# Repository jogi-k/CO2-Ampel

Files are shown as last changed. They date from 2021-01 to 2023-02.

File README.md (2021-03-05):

# CO2-Ampel

Ziel : 3 verschiedene Systeme für eine CO2-Ampel

Alle nutzen den CO2-Sensor von Sensirion, der via I2C-Bus folgende Daten ausgibt:

* CO2-Konzentration in ppm
* Temperatur in °C
* Luftfeuchte in %

Die drei Ampeln nutzen ansonsten, was der Bastler-Haushalt so hergibt.

## System 1 (ist fertig) :

Siehe [hier im Unterverzeichnis Teensy/CO2_Ampel](Teensy/CO2_Ampel/README.md)

* Teensy-LC
* 4 * 7-Segment-Anzeigen mit Neo-Pixeln, ist also gleichzeitig die Ampel, da die Farben angezeigt werden

## System 2 (ist fertig)

und sieht so aus:

* Teensy LC 
* Neo-Pixel-Ring mit 16 LEDs, pro 100 ppm 1 LED bis max 1699 ppm unterscheidbar, farbkodierte Wertebereiche
* OLED-Display 0.91" , 128 x 32, für Ausgabe der genauen CO2-Konzentration 
* Ein BCD-Dreh-Encoder für die Helligkeit der Neopixel-LEDs e Grafik-Anzeige mit Zeit ...

Siehe [hier im Unterverzeichnis Teensy/CO2_Ampel_OLed](Teensy/CO2_Ampel_OLed/README.md)

## System 3:

* Raspberry Pi (mal schauen, welcher...)
* grosse USB-Ampel von Cleware
* 3.5 " LCD für Raspi
* evt. je nach Aufstellungs-Ort, auch noch eine RTC

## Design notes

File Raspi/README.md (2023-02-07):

# CO2-Ampel am Raspberry-Pi

* Raspberry Pi
* USB-Ampel von Cleware
* CO2-Sensor SCD 30 
* Display tbd

## Software

* SCD30-I2C Python - SW : https://pypi.org/project/scd30-i2c
* USB-Ampel : https://github.com/jenszech/StatusLight
* bzw : 

## Other SCD30-Software

* Nutze inzwischen (co2-ampel-II.py) den Treiber-code von sensirion selbst

## Zweiter I2C-Bus

Moechte nun 2 (besser noch 3) SCD 30 Sensoren mal eine Woche an der frischen Luft laufen lassen um zu sehen, inwieweit sich die Messwerte angleichen.

Der Raspberry Pi hat zwei I2C-Busse eingebaut, der andere (I2C-Bus 0) muss jedoch erst per Config eingeschaltet werden.

Mehr Infos dazu : https://www.woodgears.ca/tech/i2c.html
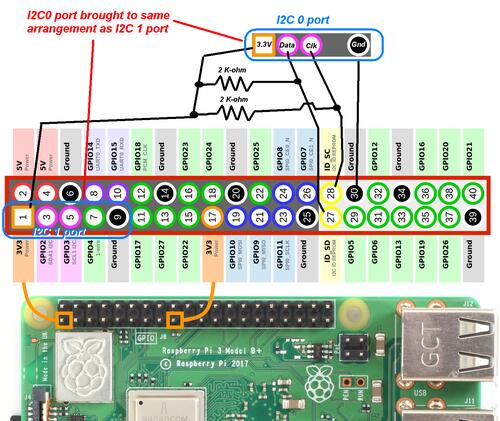
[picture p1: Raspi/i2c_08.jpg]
Bild
Anschluss : 

### Dritter I2C-Bus 

Fuer den 3ten Sensor habe ich mir einen exteren USB2I2C-Adapter besorgt.  
Mehr Infos dazu gibt es u.a im Raspberry Pi Geek Magazin:

* https://www.raspberry-pi-geek.de/ausgaben/rpg/2020/06/i-2-c-teil-31-usb-i-2-c-modul-mcp23017/
* http://www.chinalctech.com/cpzx/Programmer/Serial_Module/266.html
* 
und hier

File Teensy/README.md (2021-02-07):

# Teensy LC USB-Ampel

## 1. Teensy LC mit Neosegments

* Sensor Sensirion SCD30 für CO2-Messung
* 2 Doppelsegmente Neosegments, 7-Segment-Anzeige mit Farbe
* Das geht und ist im Einsatz in der Schule, Details siehe [hier](CO2_Ampel/README.md) 

## 2. Teensy LC mit Neopixel-Ring und kleinem OLED-Display

* Sensor Sensirion SCD30 für CO2-Messung
* Neopixel-Ring mit 16 RGB-Leds, je LED für 100 ppm
* Die LEDs wechseln natürlich auch die Farbe
* zusätzlich ein Mini-OLED-Display, das die ppm-Werte anzeigt
* Das ist gerade im Aufbau, Einzel-SW-Teile gehen schon, siehe [hier](CO2_Ampel_OLed/README.md)

## 3. Teensy LC mit ePaper-Shield 

* Epaper-shield von Crowd-Supply
* Software von, mit Patch von mir: 
* Graph-Routines von https://create.arduino.cc/projecthub/andreiflorian/tft-graphing-live-history-graphs-744f3b
* Ist noch stark im Aufbau, die Epaper-Shield-SW braucht noch nen weiteren Patch* Die Graph-Routines dienen als Inspiration, sind selbst aber etwas buggy und können so nicht verwendet werden.

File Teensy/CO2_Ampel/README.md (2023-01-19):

# Teensy LC USB-Ampel mit Neosegments

* Der Sensirion SCD30 CO2-Sensor wird mit I2C angesprochen
* dafür gibt es eine Library, SparkFun_SCD30_Arduino_Library 
* diese wurde von mir gepatcht, um mit anstatt mit der wire-I2C-library die besser für Teensy 3 / Teensy LC geeignete i2c_t3 - Library zu verwenden
* Der Patch ist inzwischen auf dem Master-Branch von Sparkfun
* Muss jedoch explizit im Headerfile eingeschaltet werden, siehe  // #define USE_TEENSY3_I2C_LIB  
* Die Anzeige wurde über die (leider nicht mehr verfügbaren) Neo-Segments von crowdsupply realisiert : [https://www.crowdsupply.com/maksmakes/neosegment](https://www.crowdsupply.com/maksmakes/neosegment)

## Das Pinout des SCD30

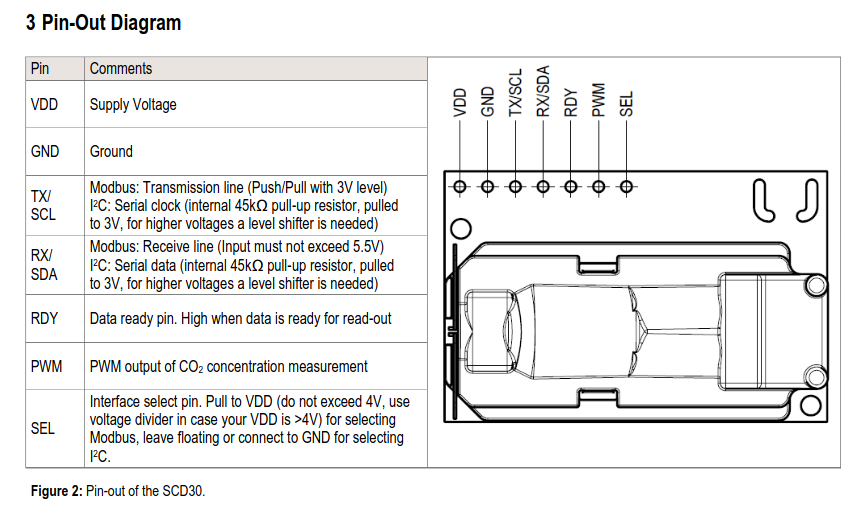
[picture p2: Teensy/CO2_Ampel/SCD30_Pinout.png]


## Layout von Fritzing

### Breadboard

Die Neosegments gibt es leider nicht in Fritzing.   
Da die elektrische Verbindung genau gleich wie bei klassischen Neopixel-Sticks ist,   
wurden diese ersatzweise für den Stromlauf/Layout verwendet.

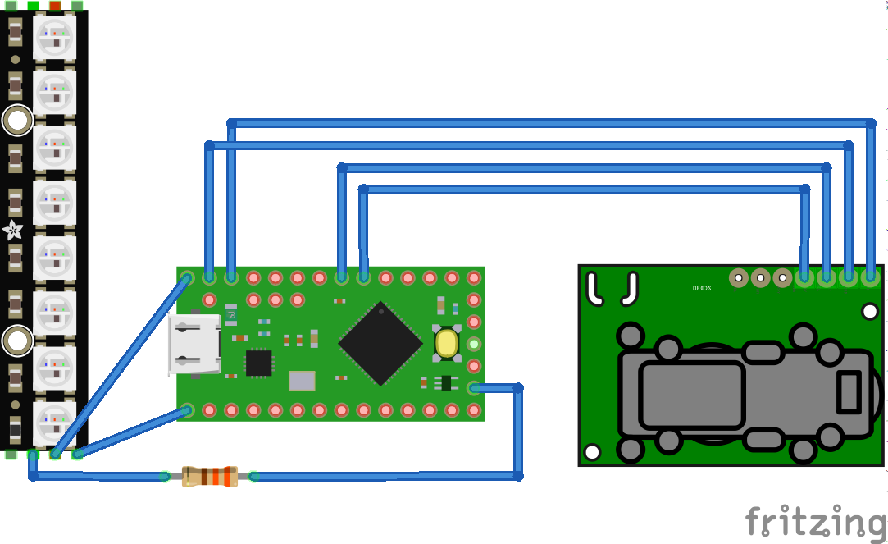
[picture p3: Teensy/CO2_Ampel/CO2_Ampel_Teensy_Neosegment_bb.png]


### Schematics

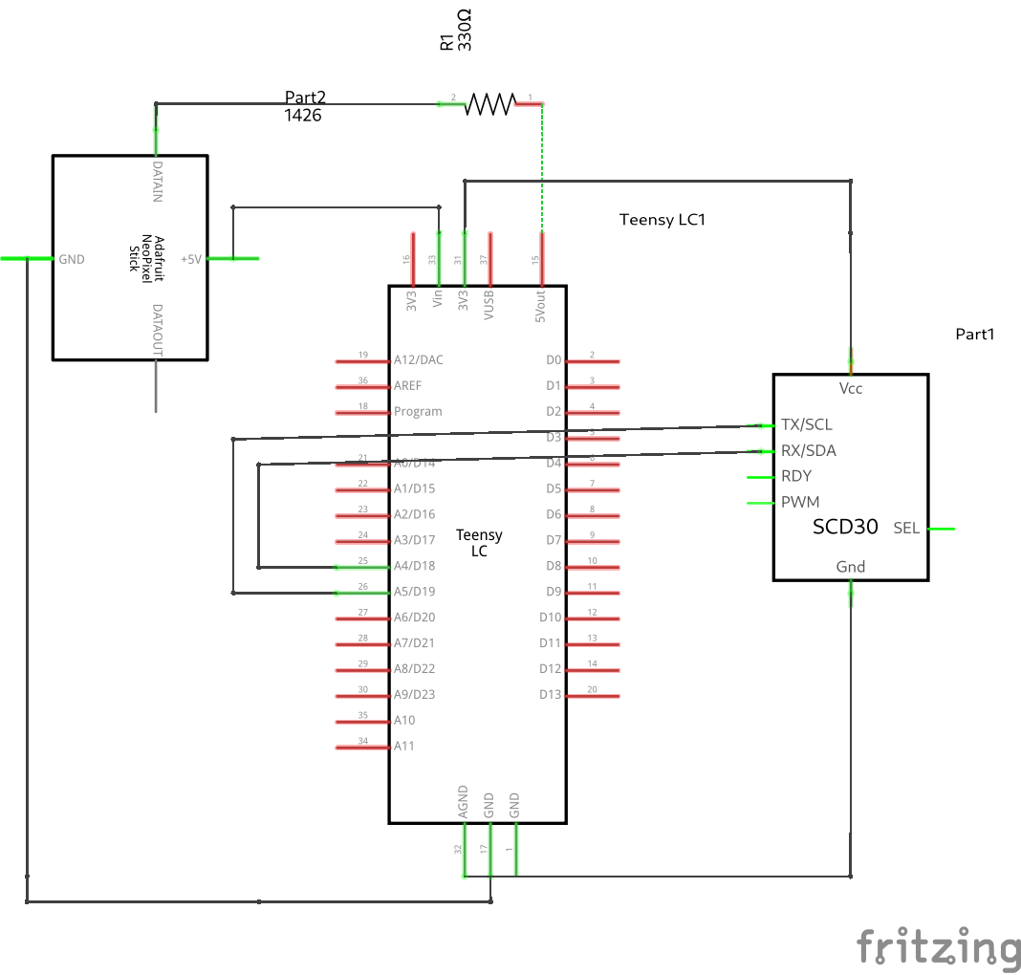
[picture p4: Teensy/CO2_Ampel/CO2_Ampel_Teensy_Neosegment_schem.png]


## Fliegender Aufbau

### Noch im grünen Bereich

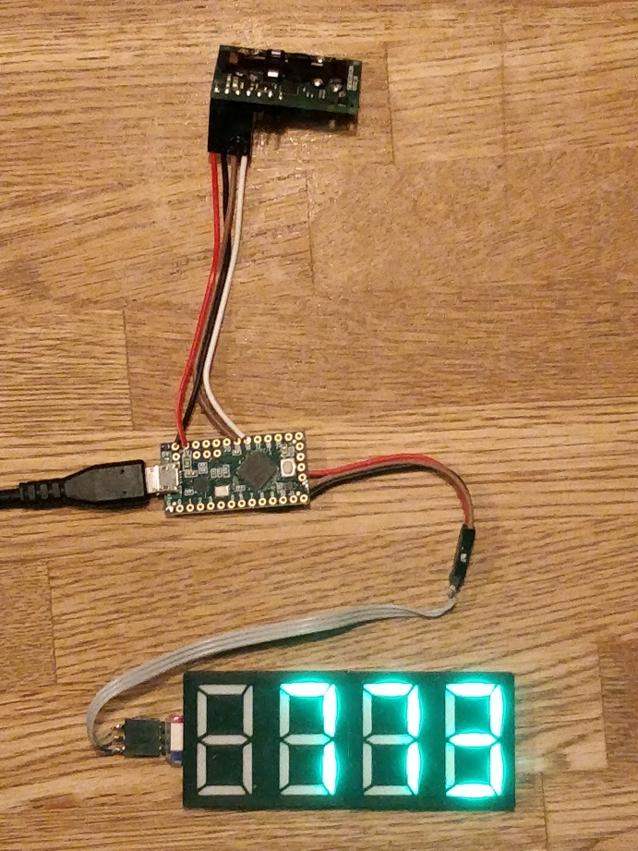
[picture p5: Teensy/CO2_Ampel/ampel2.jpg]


### Grösser 800 ppm : Gelb

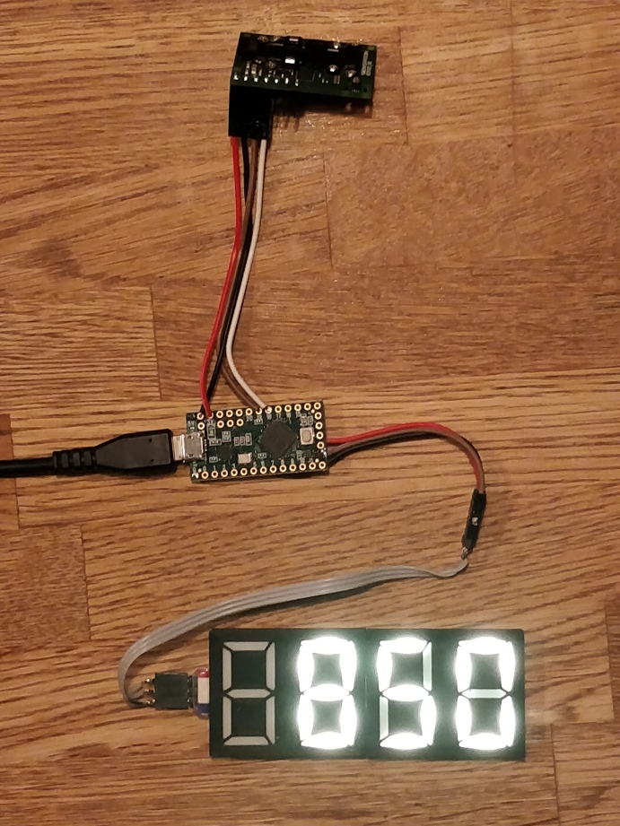
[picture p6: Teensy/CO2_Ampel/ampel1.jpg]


## Implementierungs-Details

* Es Wird alle 2 sek gemessen
* Vier Werte werden aufsummiert und daraus der Mittelwert gebildet
* Alle 8 Sekunden liegt ein neuer Mittelwert vor, der dann 8 sek lang angezeigt wird
* bis 799 ppm : Grün
* bis 999 ppm : Gelb
* bis 1199 ppm : Rot
* Grössr/gleich 1200 ppm : Rot blinkend
* Beim Einschalten liegt noch kein Wert vor: es wird 8888 in blau angezeigt

## Finaler Zusammenbau in Makerbox 

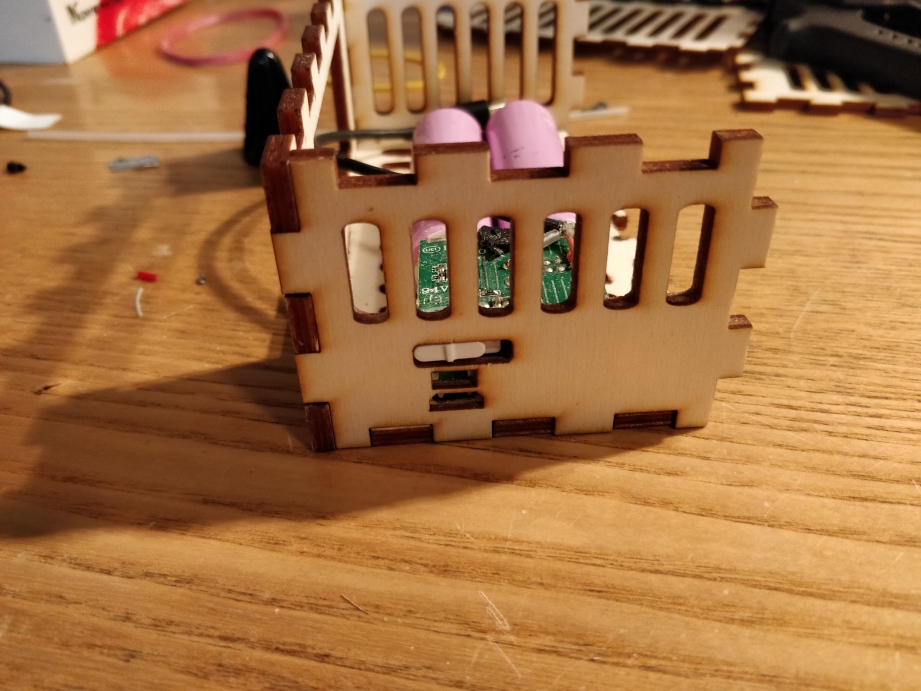
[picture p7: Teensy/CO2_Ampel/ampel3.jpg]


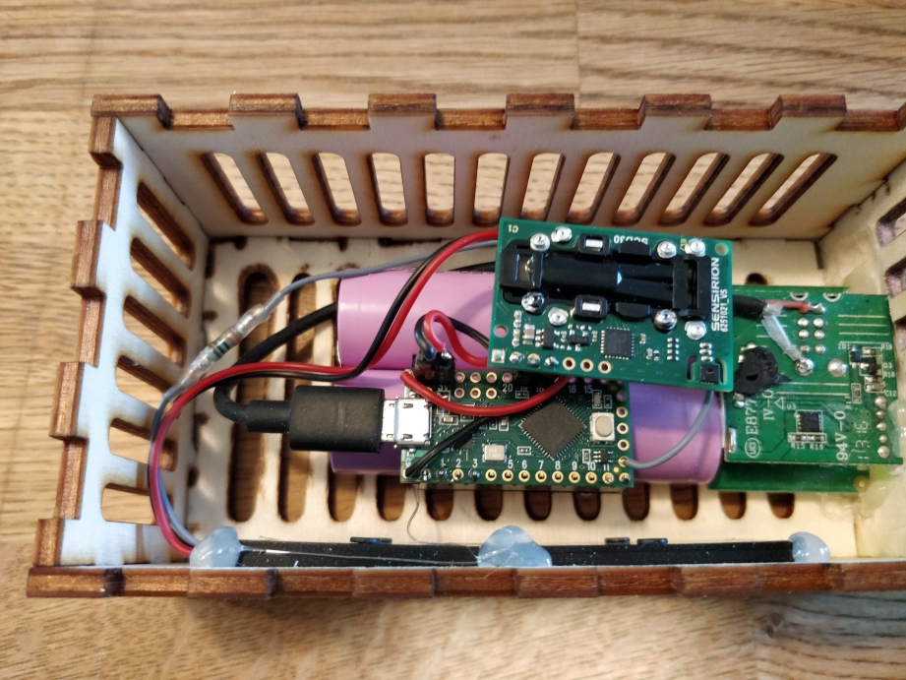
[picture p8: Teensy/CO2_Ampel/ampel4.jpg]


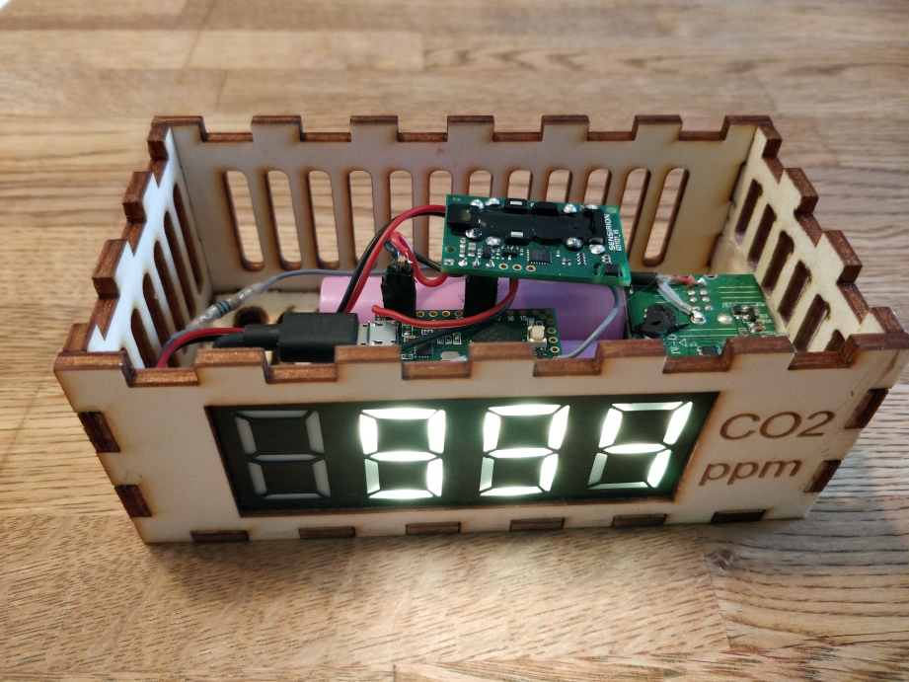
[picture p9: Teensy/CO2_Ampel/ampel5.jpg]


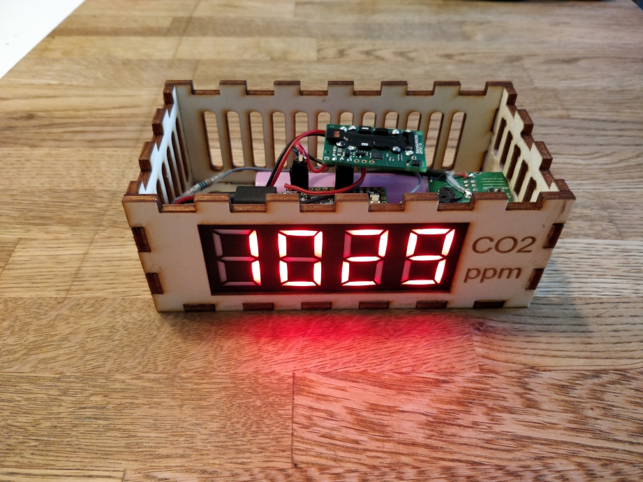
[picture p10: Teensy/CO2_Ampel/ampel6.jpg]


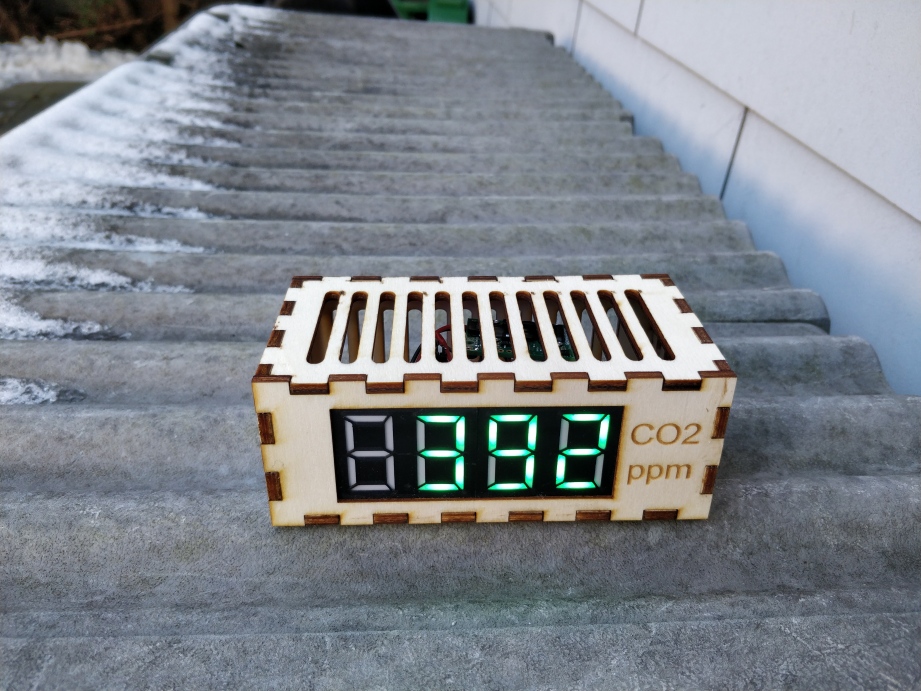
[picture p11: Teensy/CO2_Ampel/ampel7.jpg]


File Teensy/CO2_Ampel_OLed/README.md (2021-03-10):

# CO2-Ampel mit Neopixel-Ring und OLED-Display

* Sensor Sensirion SCD30 für CO2-Messung
* Neopixel-Ring mit 16 RGB-Leds, je LED für 100 ppm
* Die LEDs wechseln natürlich auch die Farbe
* zusätzlich ein Mini-OLED-Display, das die ppm-Werte anzeigt (bei Teensy LC / 3.0 bitte meinen Branch von u8g2 benutzen, der kann Teensy 3.x / LC )
* Zur Helligkeits-Regulierung des Neo-Pixel-Rings wird ein BCD-10-Stellen-Drehschalter eingesetzt.
  (In Fritzing gibt es den nur als Hexa-Dezimal von 0-F ...)
* Ich hatte Probleme mit OLED und SCD30 am selben I2C-Bus, alle Tips im Netz zum Thema I2C <=> Teensy LC haben nichts bewirkt, mein OSZI steht leider Corona-bedingt in Deutschland, darumkonnte ich nicht messen ... => Darum habe ich die beiden Devices an die beiden unterschiedlichen I2C-Busse des Teensy LC gehängt

## Layout von Fritzing 

### Fritzing-File

[CO2_Ampel_Teensy_Neopixel_OLED.fzz](pics/CO2_Ampel_Teensy_Neopixel_OLED.fzz)

### Breadboard

Auch hier , wie im "Nachbar-Projekt", den Neopixel 16er-Ring gibt es nicht, darum eben als 10er Stick.
Da die elektrische Verbindung genau gleich wie bei klassischen Neopixel-Sticks ist,   
wurden diese ersatzweise für den Stromlauf/Layout verwendet.

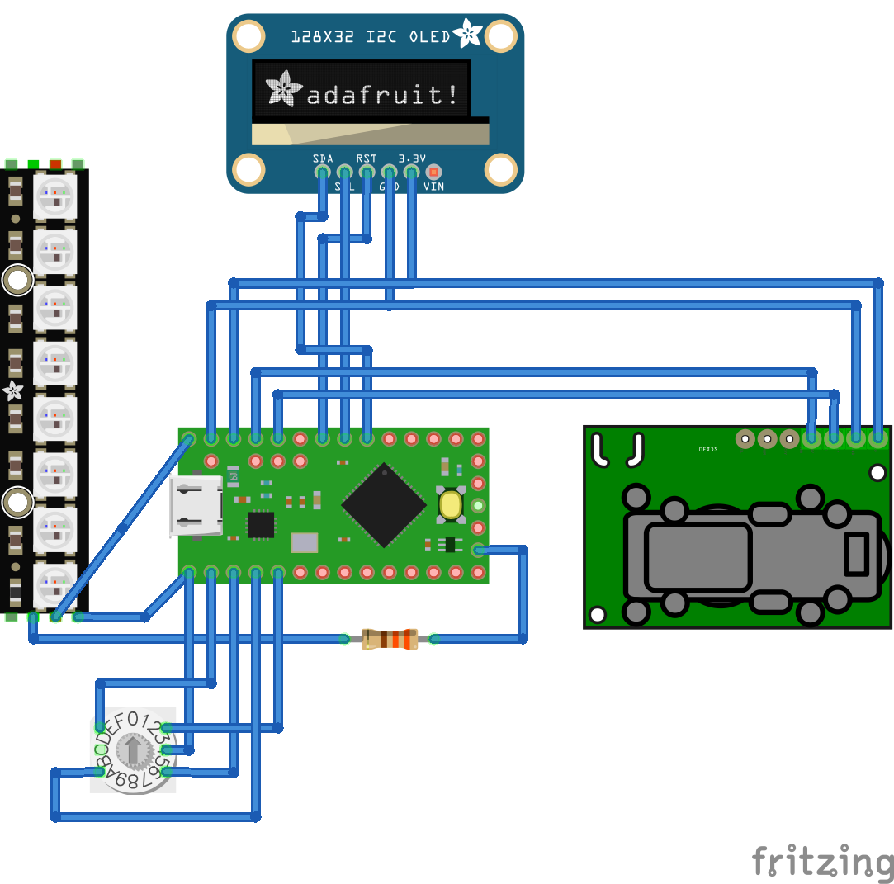
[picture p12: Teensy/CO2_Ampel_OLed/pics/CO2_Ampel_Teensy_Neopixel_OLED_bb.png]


### Schematics

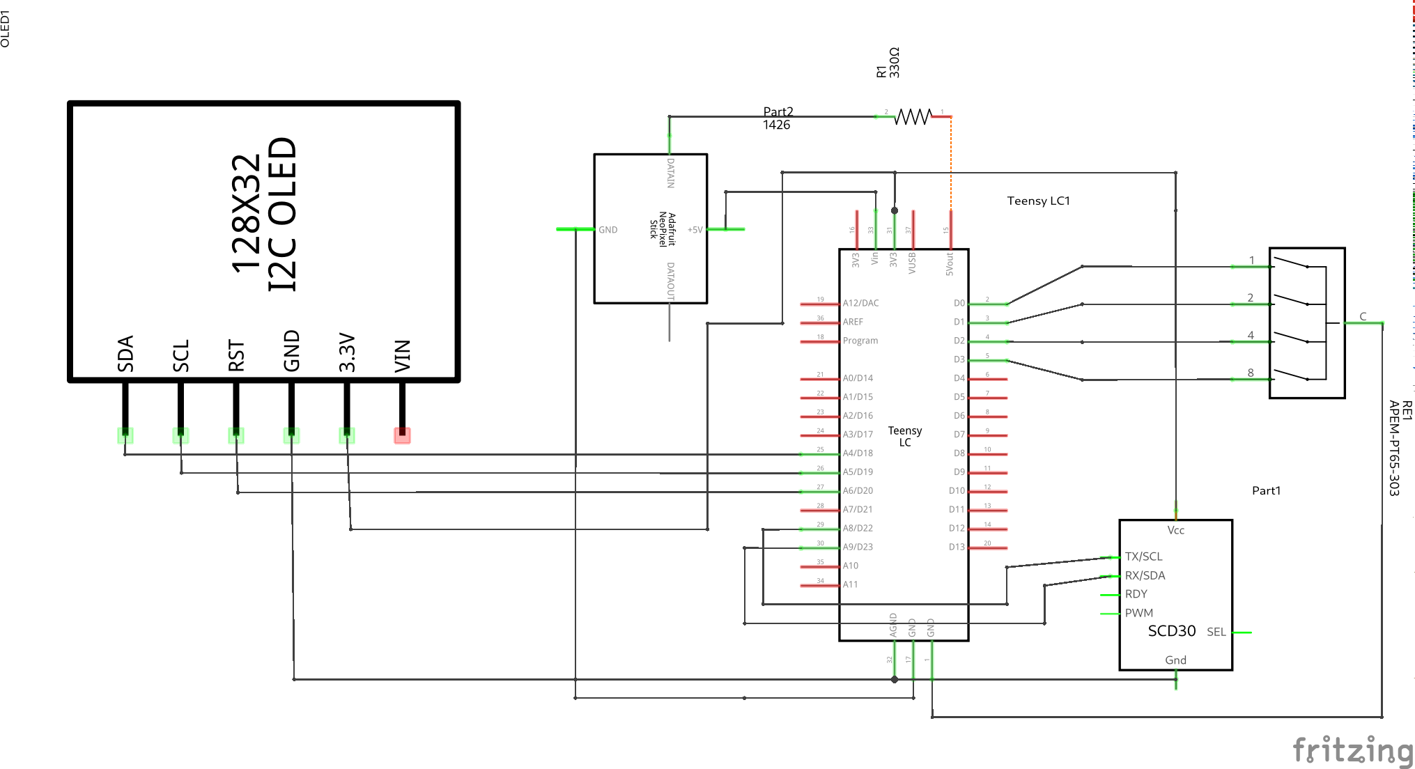
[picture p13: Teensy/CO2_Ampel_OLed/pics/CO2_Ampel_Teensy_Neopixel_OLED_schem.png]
  

## Fotos vom Aufbau

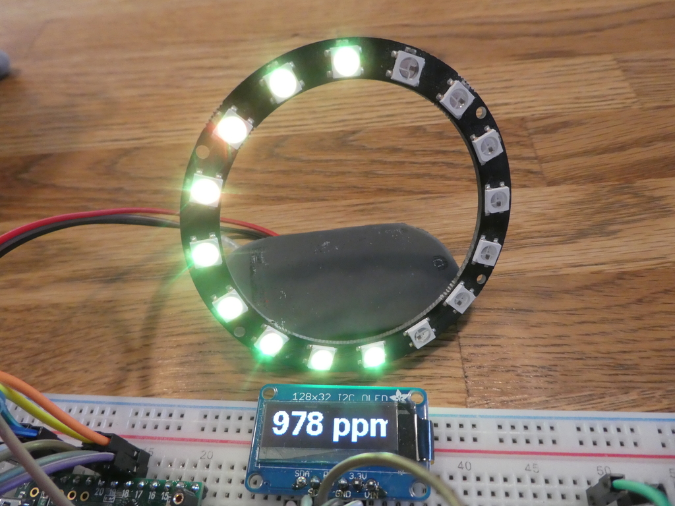
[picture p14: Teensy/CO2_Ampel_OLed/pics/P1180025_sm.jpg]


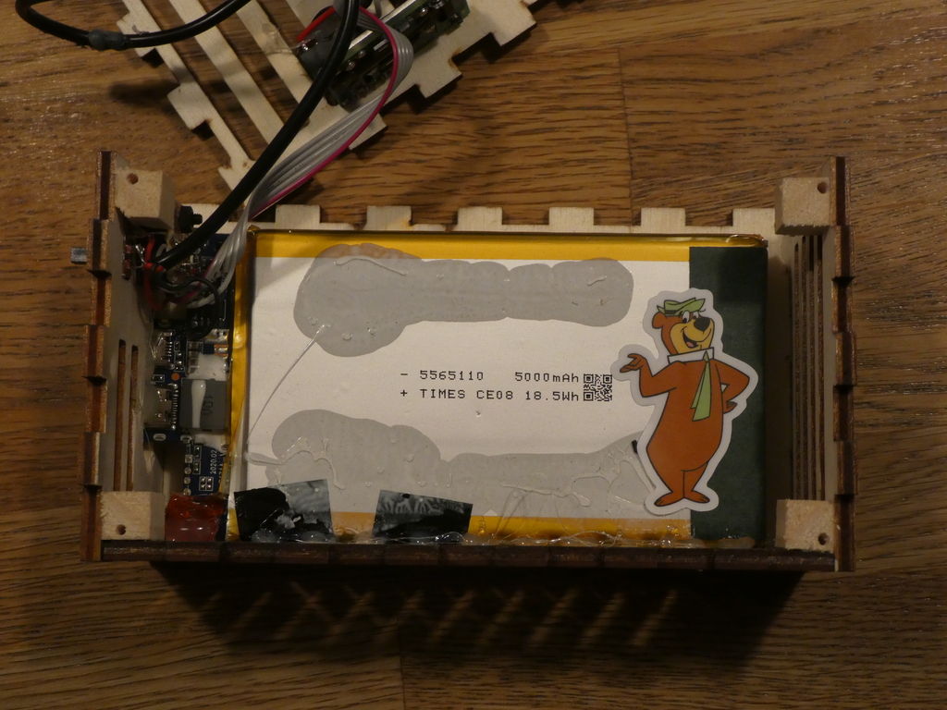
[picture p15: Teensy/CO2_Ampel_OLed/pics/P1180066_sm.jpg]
P1180066_sm


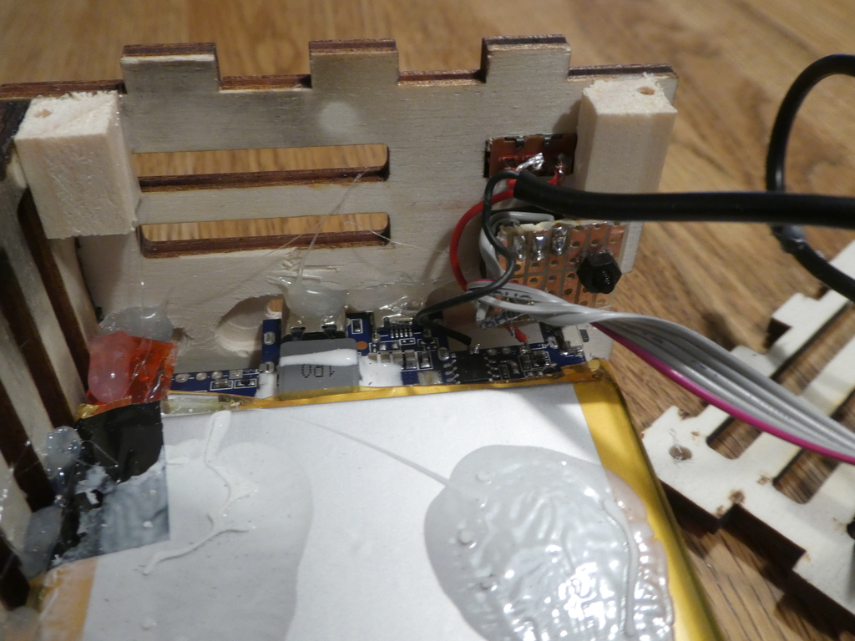
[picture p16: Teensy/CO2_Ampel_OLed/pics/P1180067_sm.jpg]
P1180067_sm


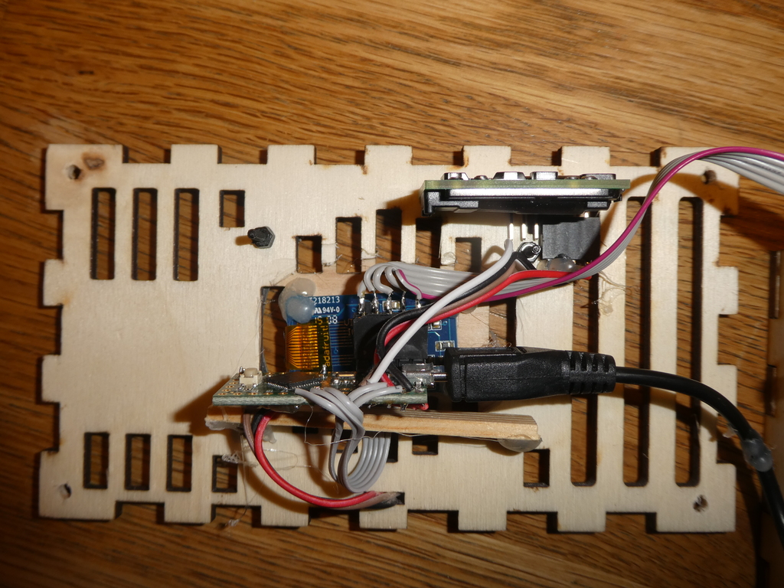
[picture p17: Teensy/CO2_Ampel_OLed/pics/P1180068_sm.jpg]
P1180068_sm


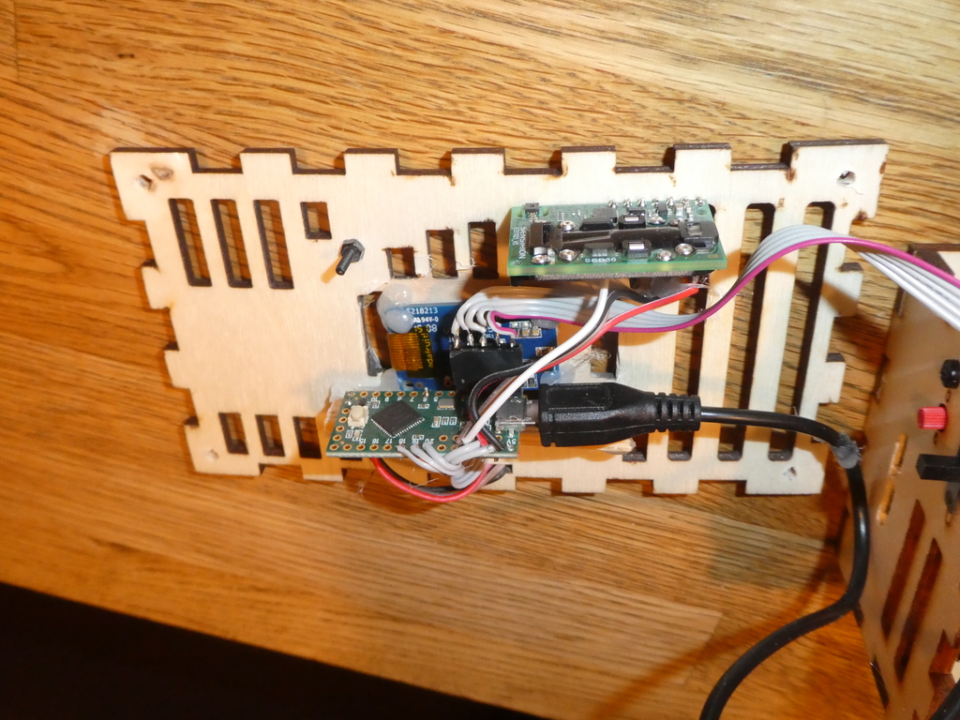
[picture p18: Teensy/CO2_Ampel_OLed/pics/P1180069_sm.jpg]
P1180069_sm


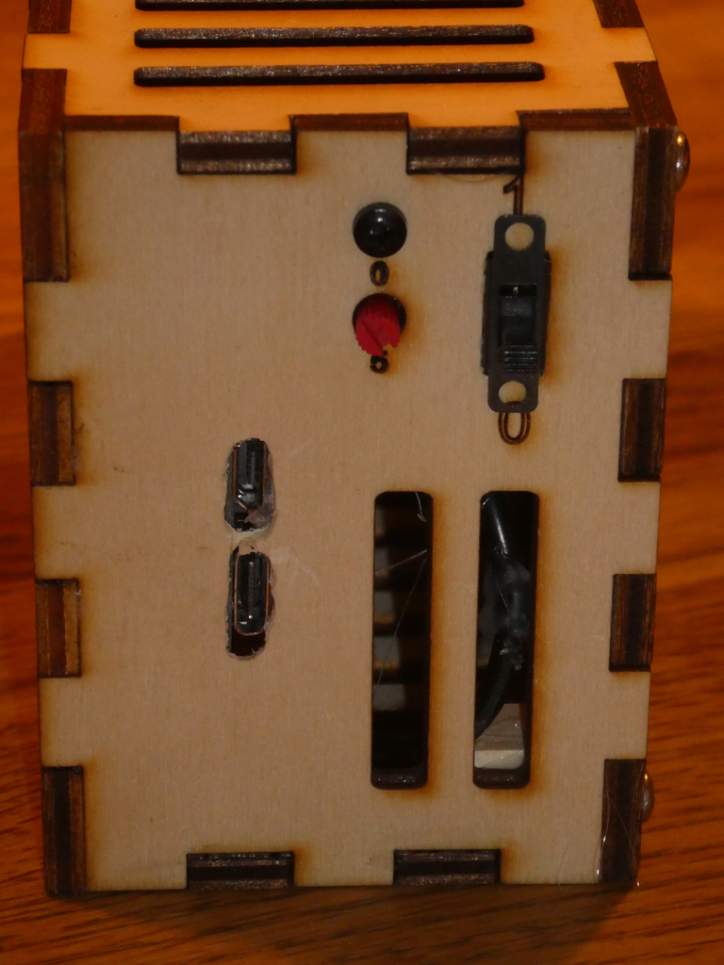
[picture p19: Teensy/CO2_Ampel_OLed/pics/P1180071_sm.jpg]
P1180071_sm


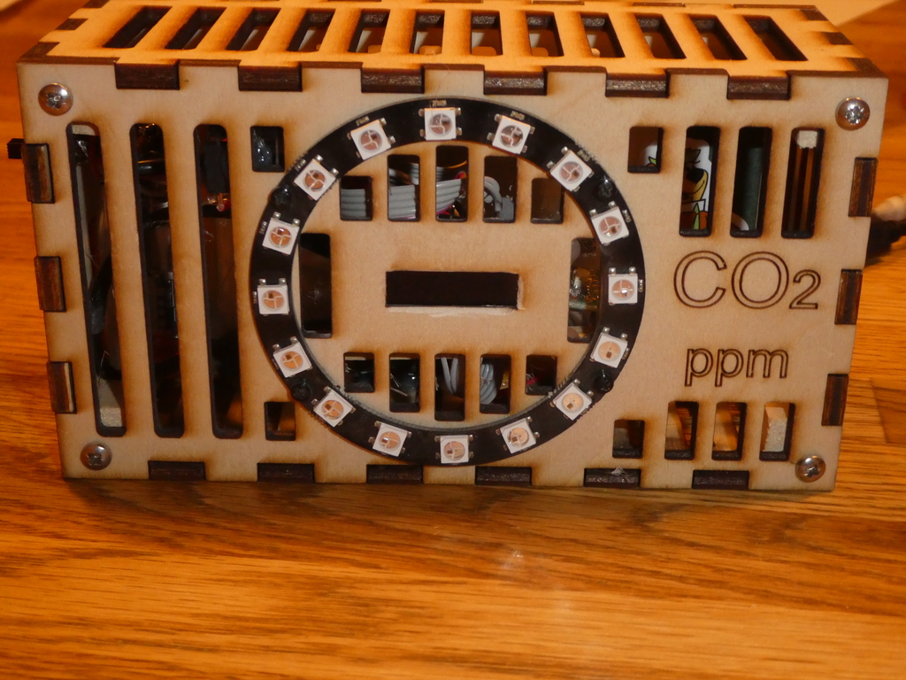
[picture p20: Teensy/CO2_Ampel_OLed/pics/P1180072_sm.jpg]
P1180072_sm


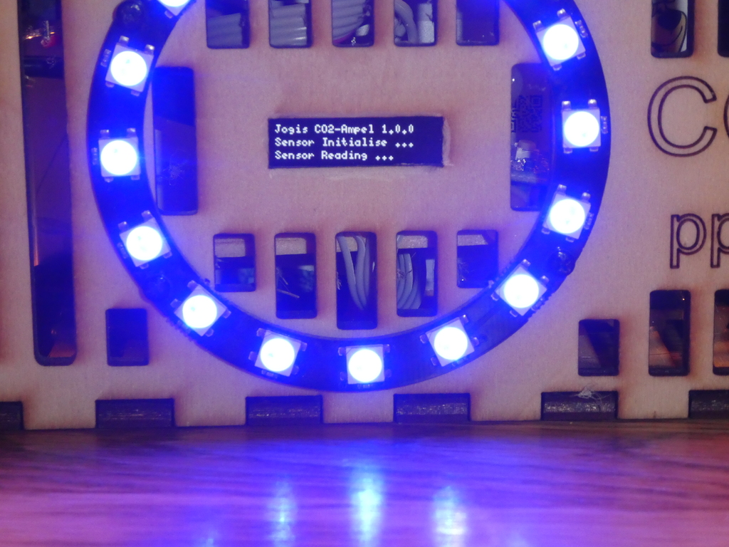
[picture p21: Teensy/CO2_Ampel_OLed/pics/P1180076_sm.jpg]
P1180076_sm


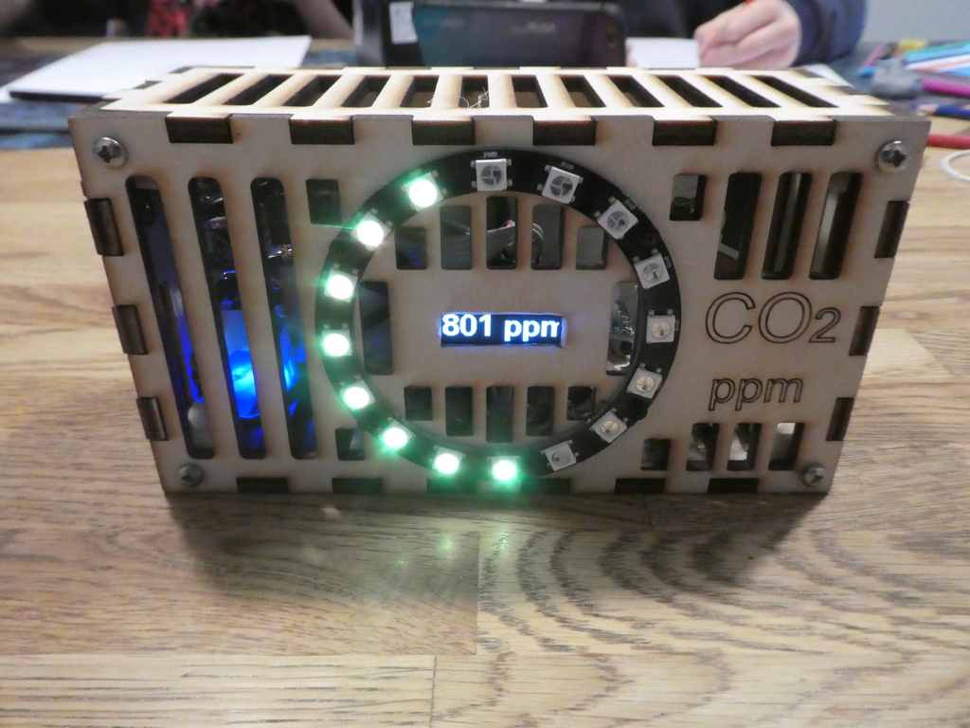
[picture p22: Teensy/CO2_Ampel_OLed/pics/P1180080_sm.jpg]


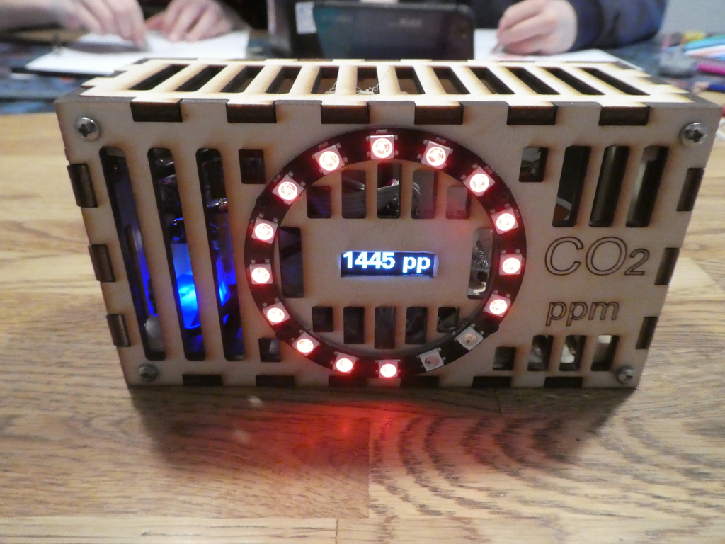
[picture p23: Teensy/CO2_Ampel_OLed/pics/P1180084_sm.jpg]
P1180084_sm


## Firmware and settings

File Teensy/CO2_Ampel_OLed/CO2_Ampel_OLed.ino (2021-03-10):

/*

  CO2_Ampel_OLed.ino


  Built for Teensy LC, but might be changed rather easy to also run on other Arduino-Compatible Boards with support for I2C and NeoPixel (at least one 5V IO-Line)
  
  - Uses an SCD30 Sensirion-Sensor for sensing CO2.
  - Uses an Adafruit 128x32-Pixel 0.91" OLED-Display for showing the exact values
  - Uses an Neo-Pixel-Ring with 16 RGB-Leds, each showing 100ppm.
  - For brightness-setting it reads a BCD-rotary-Encoder with 0-9


  The OLED-Parts of the program are derived from HelloWorld.ino from
  --- snip ---
  Universal 8bit Graphics Library (https://github.com/olikraus/u8g2/)

  Copyright (c) 2016, olikraus@gmail.com
  All rights reserved.

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
  THIS SOFTWARE IS PROVIDED BY THE COPYRIGHT HOLDERS AND 
  CONTRIBUTORS "AS IS" AND ANY EXPRESS OR IMPLIED WARRANTIES, 
  INCLUDING, BUT NOT LIMITED TO, THE IMPLIED WARRANTIES OF 
  MERCHANTABILITY AND FITNESS FOR A PARTICULAR PURPOSE ARE 
  DISCLAIMED. IN NO EVENT SHALL THE COPYRIGHT HOLDER OR 
  CONTRIBUTORS BE LIABLE FOR ANY DIRECT, INDIRECT, INCIDENTAL, 
  SPECIAL, EXEMPLARY, OR CONSEQUENTIAL DAMAGES (INCLUDING, BUT 
  NOT LIMITED TO, PROCUREMENT OF SUBSTITUTE GOODS OR SERVICES; 
  LOSS OF USE, DATA, OR PROFITS; OR BUSINESS INTERRUPTION) HOWEVER 
  CAUSED AND ON ANY THEORY OF LIABILITY, WHETHER IN CONTRACT, 
  STRICT LIABILITY, OR TORT (INCLUDING NEGLIGENCE OR OTHERWISE) 
  ARISING IN ANY WAY OUT OF THE USE OF THIS SOFTWARE, EVEN IF 
  ADVISED OF THE POSSIBILITY OF SUCH DAMAGE.  

  --- snap ---

For details of the schematics, please see on the github-Repository:
https://github.com/jogi-k/CO2-Ampel/tree/main/Teensy/CO2_Ampel_OLed


*/


#define VERSION_STRING "1.0.0"

/* Features of the Hardware => Functionality in SW */
#define NEOPIXEL_STRIP_CONNECTED
// #define NEOSEGMENTS_CONNECTED 
#define ADAFRUIT_OLED_CONNECTED
#define ROTARY_BCD_SWITCH_CONNECTED

#ifdef NEOPIXEL_STRIP_CONNECTED 
#ifdef NEOSEGMENTS_CONNECTED
#error "Either NEOPIXEL or NEOSEGMENTS, not both can be connected"
#endif /* NEOSEGMENTS_CONNECTED */
#endif /* NEOPIXEL_STRIP_CONNECTED  */

#include <i2c_t3.h>

#ifdef NEOPIXEL_STRIP_CONNECTED 
#include <Adafruit_NeoPixel.h>
#endif /* NEOPIXEL_STRIP_CONNECTED */

#ifdef NEOSEGMENTS_CONNECTED
#include <Neosegment.h>
#error "not yet implemented in this sketch, please use first version of sketch in sibling directory"
#endif /* NEOSEGMENTS_CONNECTED */


#ifdef ADAFRUIT_OLED_CONNECTED
// when running on Teensy >= 3 or Teensy LC you need to set the define IN the Library
#include <U8g2lib.h>
#endif /* ADAFRUIT_OLED_CONNECTED */

// when running on Teensy >= 3 or Teensy LC you need to set the define IN the Library
#include "SparkFun_SCD30_Arduino_Library.h" //Click here to get the library: http://librarymanager/All#SparkFun_SCD30


#define NEO_COLOR_RED    0xFF0000
#define NEO_COLOR_YELLOW 0xFFFF00
#define NEO_COLOR_GREEN  0x00FF00
#define NEO_COLOR_BLUE   0x0000FF

#define BRIGHTNESS_PER_DIGIT 15  // BCD-Rotary-Coder gives 0..9, Max Brightness is 255. 15 * 9 gives 135, which is really bright already


#define RGB_PIN 17
#define AMOUNT_RGB_LEDS  16

#ifdef NEOPIXEL_STRIP_CONNECTED 
Adafruit_NeoPixel strip = Adafruit_NeoPixel(AMOUNT_RGB_LEDS, RGB_PIN, NEO_GRB + NEO_KHZ800);
#endif /* NEOPIXEL_STRIP_CONNECTED */

#ifdef ADAFRUIT_OLED_CONNECTED
U8G2_SSD1306_128X32_UNIVISION_F_HW_I2C u8g2( U8G2_R0, /* reset=*/20 , /* clock=*/ SCL, /* data=*/ SDA);
#endif /* ADAFRUIT_OLED_CONNECTED */

SCD30 airSensor;


void setup(void) {

    /* The BCD rotary switch */
    RotaryBCD_Init();

    delay( 1000 );
    /* Debugging */
    Serial.begin(115200);
    Serial.println("CO2-Ampel");

    /* Wire1 goes to SCD30, Wire1 has to be initialised before initialising SCD30  */
    Wire1.begin();
    
    /* The OLED-Display */
#ifdef  ADAFRUIT_OLED_CONNECTED
    u8g2.begin();
    u8g2.clearDisplay();  
#endif /* ADAFRUIT_OLED_CONNECTED */

    /* The NEO-Pixel-Ring */
#ifdef NEOPIXEL_STRIP_CONNECTED 
    strip.begin();
    strip.setBrightness( RotaryBCD_GetVal() * BRIGHTNESS_PER_DIGIT );
    strip.show();
#endif /* NEOPIXEL_STRIP_CONNECTED */

    /* The SCD30-Air-Sensor */
    String MyString = "Jogis CO2-Ampel ";
    MyString.append(VERSION_STRING);
    ShowSmallOnOLED(MyString, 0 );
    delay ( 2000 );
    ShowSmallOnOLED("Sensor Initialise ...", 1 );
    Serial.println("Sensor Initialise...");
    Wire1.setClock (100000);
    delay (2000);
    if (airSensor.begin( Wire1 ) == false) 
    {
        Serial.println("Air sensor not detected. Please check wiring. Freezing...");
        ShowBigOnOLED("Error 1");
        showErrorOnStrip();
        while (1)
            ;
    }
    ShowSmallOnOLED("Sensor Reading ...", 2 );
    Serial.println("Sensor Reading..."); 
}

void loop(void) {
    static int color = 0;
    static int err_count = 0;
    bool flashing = false; 
    static int mean_ppm = 0;
    
    if ( airSensor.dataAvailable()) {
        SerialDebugSensorVals( );
        int curr_ppm = airSensor.getCO2();  
        mean_ppm = CalcNewMeanVal( curr_ppm );
        err_count = 0;
    }
    else {
        err_count++;
        if( (err_count % 10 ) == 0 ){
            Wire1.resetBus();
        } 
        if( err_count > 60 ){
            ShowBigOnOLED("Error 2");
            showErrorOnStrip();
            while (1)
            ;
        }
    }
    flashing = CalcFlashingAndColor( &color, mean_ppm) ;
    if ( mean_ppm != 8888 ){    
        String myString = String(mean_ppm) + " ppm";
        ShowBigOnOLEDWithFlashing( myString , flashing );
    }
    ShowValueAndFlashOnNeoStripesOrSegments( color, flashing, mean_ppm );
    delay(500);  
}


int last_mean_val = 0;
int last_millis;
void ShowValueAndFlashOnNeoStripesOrSegments( int color, bool flashing, int mean_val ){
    int max_led;
    max_led = mean_val / 100;
    if (last_mean_val != mean_val ){
        last_mean_val = mean_val;
        last_millis = millis();
        colorShow( color, 0, max_led); 
    }
    else if( flashing ){
        int curr_millis = millis();
        int delta_millis = curr_millis - last_millis;
        if( delta_millis > 1000 ){
            last_millis = millis();
            colorShow( color, 0, max_led); 
        }
        else if (delta_millis > 500 ){
            colorShow( 0, 0, max_led); 
        }    
    }
}


/**********************************/
/* Color and Flashing-Calculation */
/**********************************/
bool CalcFlashingAndColor( int *color, int ppm_in ){ 
    bool flashing = false;

    if( ppm_in == 8888 ){  // special handling when starting, value is 8888
        *color =  NEO_COLOR_BLUE;
        return false;
    }
    if( ppm_in  >= 1200 ){
        *color = NEO_COLOR_RED;
        flashing = true;
    }
    else if (ppm_in >= 1000 ){
        *color = NEO_COLOR_RED;
        flashing = false;
    }
    else if (ppm_in >= 800 ){
        *color = NEO_COLOR_YELLOW;
        flashing = false;
    }
    else { 
        *color = NEO_COLOR_GREEN; 
        flashing = false;
    }
    return flashing;
}

/**************************/
/* Mean-Value Calc        */
/**************************/
int  mean_val = 8888;
long new_mean_val = 0;
int  mean_count = 0;

int CalcNewMeanVal( int NewVal ){
    new_mean_val += NewVal;
    mean_count++;
    if( mean_count == 4 ){
        mean_val = new_mean_val / 4; 
        mean_count = 0;
        new_mean_val = 0;
    }
    return mean_val;
}


/**************************/
/* The Rotary BCD Encoder */
/**************************/
/* Init */
void RotaryBCD_Init( void ){
#ifdef ROTARY_BCD_SWITCH_CONNECTED
    pinMode(0, INPUT_PULLUP);
    pinMode(1, INPUT_PULLUP);
    pinMode(2, INPUT_PULLUP);
    pinMode(3, INPUT_PULLUP);
#endif /* ROTARY_BCD_SWITCH_CONNECTED */
}

/* Get Value */
int RotaryBCD_GetVal( void ){
#ifdef ROTARY_BCD_SWITCH_CONNECTED
    int Value = (!digitalRead(3)) * 8  +
                (!digitalRead(2)) * 4 +
                (!digitalRead(1)) * 2 +
                (!digitalRead(0)) ;
    return Value;
#else
    return 5;
#endif
}


/**************************/
/* The OLED-Display       */
/**************************/

/* Show small strings on the OLED-Display */
void ShowSmallOnOLED( String What, int Line ){
#ifdef ADAFRUIT_OLED_CONNECTED
    char myArray[40];
    if( Line == 0 )
        u8g2.clearBuffer();                    // clear the internal memory
    u8g2.setFont(u8g2_font_5x8_tf);   // choose a suitable font
    What.toCharArray(myArray, 40);
    if( Line == 0 )
        u8g2.drawStr(5,10,myArray );    // write something to the internal memory
    else if (Line == 1)
        u8g2.drawStr(5,20,myArray );    // write something to the internal memory
    else 
        u8g2.drawStr(5,30,myArray );    // write something to the internal memory
    u8g2.sendBuffer();                  // transfer internal memory to the display
#endif /* ADAFRUIT_OLED_CONNECTED */

}

void ShowBigOnOLED( String What ){
#ifdef ADAFRUIT_OLED_CONNECTED
    char myArray[20];
    u8g2.clearBuffer();                    // clear the internal memory
    u8g2.setFont(u8g2_font_fub25_tf);   // choose a suitable font
    What.toCharArray(myArray, 20);
    u8g2.drawStr(1,26,myArray );    // write something to the internal memory
    u8g2.sendBuffer();                  // transfer internal memory to the display
#endif /* ADAFRUIT_OLED_CONNECTED */

}




int last_millis_oled=0;
/* Show one big string on the OLED-Display */
void ShowBigOnOLEDWithFlashing( String What , bool flashing ){
   
    if( flashing ){
        int curr_millis_oled = millis();
        int akt_delta = curr_millis_oled  - last_millis_oled;
        if ( akt_delta > 1000 ){
            last_millis_oled = millis();
            ShowBigOnOLED( What );
        }
        else if ( akt_delta > 500 ){
            ShowBigOnOLED( "          " );       
        }
    }
    else {
        ShowBigOnOLED( What );
    }
}


/**************************/
/* The NEO-Pixel-Stripe   */
/**************************/

/* Shows in the given color, up to given LED, can animate LED by LED with the given delay  */ 
void colorShow(uint32_t c, uint8_t wait, uint32_t max_pixel) {
#ifdef NEOPIXEL_STRIP_CONNECTED 
    if( max_pixel > strip.numPixels() ){
        max_pixel = strip.numPixels();
    } 
    strip.setBrightness( RotaryBCD_GetVal() * BRIGHTNESS_PER_DIGIT );         
    for(uint16_t i=0; i<max_pixel ; i++) {
      strip.setPixelColor(i, c);
      strip.show();
      delay(wait);
    }
    for(uint16_t i=max_pixel; i<strip.numPixels(); i++){
        strip.setPixelColor(i, 0);
        strip.show();
    }
#endif /* NEOPIXEL_STRIP_CONNECTED */

}

/* Shows in the given color, all LEDs, can animate LED by LED with the given delay */ 
void colorWipe(uint32_t c, uint8_t wait) {
#ifdef NEOPIXEL_STRIP_CONNECTED 
  for(uint16_t i=0; i<strip.numPixels(); i++) {
      strip.setPixelColor(i, c);
      strip.show();
      delay(wait);
  }
#endif /* NEOPIXEL_STRIP_CONNECTED */
}

/* Shows every second LED in RED to indicate an error */ 
void showErrorOnStrip( void ) {
#ifdef NEOPIXEL_STRIP_CONNECTED 
    for(uint16_t i=0; i<strip.numPixels(); i++) {
        if( i % 2)
            strip.setPixelColor(i, NEO_COLOR_RED );
        else
            strip.setPixelColor(i, 0 );
        strip.show();
  }
#endif /* NEOPIXEL_STRIP_CONNECTED */
}


/**************************/
/* Serial Debugging       */
/**************************/
/* Prints the values of the AIR-Sensor via serial  */ 
void SerialDebugSensorVals( void ){
    Serial.print("co2(ppm):");
    Serial.print( airSensor.getCO2());

    Serial.print(" temp(C):");
    Serial.print(airSensor.getTemperature(), 1);

    Serial.print(" humidity(%):");
    Serial.print(airSensor.getHumidity(), 1);

    Serial.println();
}

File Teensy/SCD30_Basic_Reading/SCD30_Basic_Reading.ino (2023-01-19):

/*
  Reading CO2, humidity and temperature from the SCD30
  By: Nathan Seidle
  SparkFun Electronics
  Date: May 22nd, 2018
  License: MIT. See license file for more information but you can
  basically do whatever you want with this code.
  Feel like supporting open source hardware?
  Buy a board from SparkFun! https://www.sparkfun.com/products/15112
  This example prints the current CO2 level, relative humidity, and temperature in C.
  Hardware Connections:
  Attach RedBoard to computer using a USB cable.
  Connect SCD30 to RedBoard using Qwiic cable.
  Open Serial Monitor at 115200 baud.
*/

#include <i2c_t3.h>

#include "SparkFun_SCD30_Arduino_Library.h" //Click here to get the library: http://librarymanager/All#SparkFun_SCD30
SCD30 airSensor;

void setup()
{
  delay(10000);
  Serial.begin(115200);
  Serial.println("SCD30 Example");
  Wire1.begin();

  if (airSensor.begin(Wire1) == false)
  {
    Serial.println("Air sensor not detected. Please check wiring. Freezing...");
    while (1)
      ;
  }
  
    Serial.print("Auto calibration set to ");
    if (airSensor.getAutoSelfCalibration() == true)
        Serial.println("true");
    else 
    {
        Serial.println("false");
        Serial.println("Going to enable it ");
        if ( airSensor.setAutoSelfCalibration( true) == true )
            Serial.println("Enabled it ");
        else
            Serial.println("Could not enabled it ");
    }    
       uint16_t settingVal; // The settings will be returned in settingVal
    
    if (airSensor.getForcedRecalibration(&settingVal) == true) // Get the setting
    {
      Serial.print("Forced recalibration factor (ppm) is ");
      Serial.println(settingVal);
    }
    else
    {
      Serial.print("getForcedRecalibration failed! Freezing...");
      while (1)
        ; // Do nothing more
    }

    if (airSensor.getMeasurementInterval(&settingVal) == true) // Get the setting
    {
      Serial.print("Measurement interval (s) is ");
      Serial.println(settingVal);
    }
    else
    {
      Serial.print("getMeasurementInterval failed! Freezing...");
      while (1)
        ; // Do nothing more
    }

    if (airSensor.getTemperatureOffset(&settingVal) == true) // Get the setting
    {
      Serial.print("Temperature offset (C) is ");
      Serial.println(((float)settingVal) / 100.0, 2);
    }
    else
    {
      Serial.print("getTemperatureOffset failed! Freezing...");
      while (1)
        ; // Do nothing more
    }

    if (airSensor.getAltitudeCompensation(&settingVal) == true) // Get the setting
    {
      Serial.print("Altitude offset (m) is ");
      Serial.println(settingVal);
    }
    else
    {
      Serial.print("getAltitudeCompensation failed! Freezing...");
      while (1)
        ; // Do nothing more
    }

    if (airSensor.getFirmwareVersion(&settingVal) == true) // Get the setting
    {
      Serial.print("Firmware version is 0x");
      Serial.println(settingVal, HEX);
    }
    else
    {
      Serial.print("getFirmwareVersion! Freezing...");
      while (1)
        ; // Do nothing more
    }

    Serial.print("Auto calibration set to ");
    if (airSensor.getAutoSelfCalibration() == true)
        Serial.println("true");
    else
        Serial.println("false");

    //The SCD30 has data ready every two seconds

  //The SCD30 has data ready every two seconds
}

void loop()
{
  if (airSensor.dataAvailable())
  {
    Serial.print("co2(ppm):");
    Serial.print(airSensor.getCO2());

    Serial.print(" temp(C):");
    Serial.print(airSensor.getTemperature(), 1);

    Serial.print(" humidity(%):");
    Serial.print(airSensor.getHumidity(), 1);

    Serial.println();
  }
  else
    Serial.println("Waiting for new data");

  delay(500);
}

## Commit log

2020-12-30 Adaptions for temp and better usage of x-Axis
2021-01-05 Some changes, improvements on graph, still does not work
    [ePaperTempPlayground.ino]
2021-01-05 Now Teensy LC with Neopixel 7-Segments , aka Neosegments
2021-01-07 cleanup code and create some documentation
    [CO2_Ampel_Teensy_Neosegment.fzz]
2021-01-08 Fix digitIndex-Bug, this was unfortunately an intermediate save...
    [CO2_Ampel.ino]
2021-02-13 Experiments for moving to i2c_lib for Teensy
2021-02-14 Still problems with i2c_t3 vs Wire, investigating
    [CO2_Ampel_OLed.ino]
2021-02-17 Playground for Sensor added
2021-03-05 New implementation, documentation etc
    [CO2_Ampel_Teensy_Neopixel_OLED.fzz]
2021-03-05 Updated Readme with new Teensy-Version
2023-01-19 Some basic stuff for reading with Teensy
2023-02-04 2ter I2C-Bus und zweites (copy-paste) programm fuer I2C0
2023-02-05 Infos ueber 2ten und 3ten I2C-Bus
